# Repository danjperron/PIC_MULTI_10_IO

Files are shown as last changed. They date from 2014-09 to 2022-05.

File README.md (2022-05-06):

PIC_MULTI_10_IO
===============

RS-485 module with 10  I/O multi-function

Multi-Purpose RS-485 with Modbus Protocol using a small cpu PIC16F1827

Project compiled using MPlab X IDE with XC8 V2.36 using C90 standard (compiler optimization=2)

  The PIC  C code 
  
    - main.c             Main Source code.
    - IOCycle.c          Sensor cycle management.
    - DHT22.c            DHT11, DHT22 and AM2303 Temperature Sensor code.
    - DS18B20.c          Digital DS18B20 sensor code.
    - RCServo.c          R/C servo  PWM code.
    - CAPSENSE.c         Capacitive sensor code.
    - CRC16.c            Modbus Cyclic redundancy check code.

  The PIC Header
  
    - IOCycle.h
    - DHT22.h
    - DS18B20.h
    - RCServo.h
    - IOCONFIG.h         IO , Cpu Frequency and timing information header.

  The binary file
  
  - MULTI_IO_10_XT_1.06_9600.hex
  - MULTI_IO_10_XT_1.06_57600.hex

  No crystal
  - MULTI_IO_10_NOXT_1.06_57600.hex   
  - MULTI_IO_10_NOXT_1.06_9600.hex

  Add-on file for Raspberry Pi

    - PicModule.py        Python class interface.
    - configPIC.c         Application to configure each remote module.
    - test.c              Example code to interface the remote with libmodbus in C.

  The Schematic

    - MultiIO10.png  Electronic schematic.

  The GPL License

    - gpl.txt

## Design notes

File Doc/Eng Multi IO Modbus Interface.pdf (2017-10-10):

# MULTI IO 10

# RS-485 IO Interface with configurable function using a small Microchip cpu

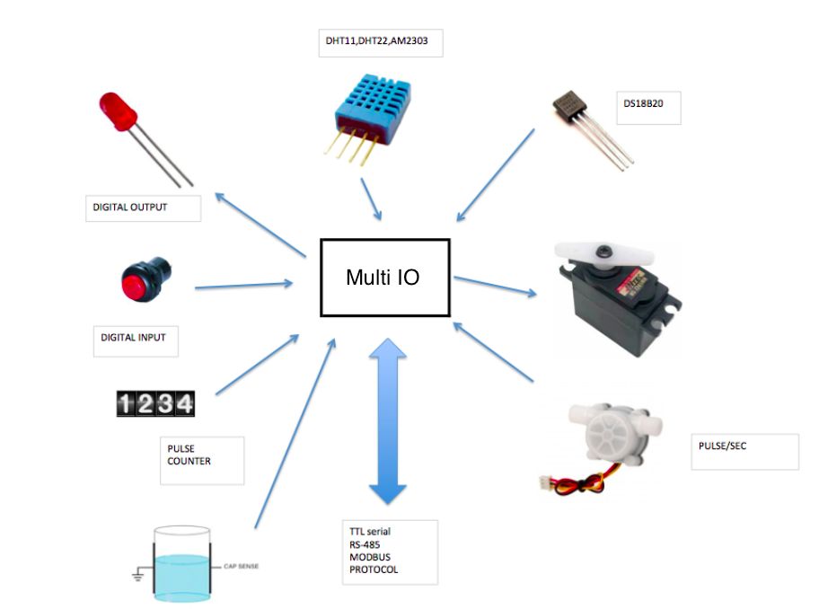
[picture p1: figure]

Daniel Perron
Avril 2014

## Preface

Often I need to have a special interface to connect a sensor far away of the computer which will interpret the signal. But instead of re-inventing the wheel all the times, I decide to create a small pcb with build-in screwable terminal with versatile IO configuration. This way I could change, by software, the functionalities of the pins.
I was tired of using an arduino, compile a special code and solder wire between the sensor and the arduino header.

I decide to use the RS-485 multipoint system which allow me to connect more than one module on the same cable and not been limited by short distance cable. The RS-485 cable could be extend up to 1200 meter without repeater.

Since Modbus protocol library was already available for Python and ‘C’, I decide to make the module compatible with Modbus. In theory, up to 247 modules could reside on the same bus but because of driver constraint, 64 modules is more or less the
maximum.

The 18 pins DIP PIC16F1827 will be the core cpu with 10 inputs or outputs signal with differents type of configuration possible,

- A/D 10 bits with 4 levels of voltage reference.
- DHT11, DHT22 ou AM2303 sensor interface.
- DS18B20 sensor interface.
- Internal capacitive frequency reader.
- Frequency and pulse counter reader.
- Simple input or output signal.
- 4 PWM output using 10 bits resolution.
- R/C PWM servo control.

## Step 1 - Raspberry Pi setup

An USB to Rs-485 interface it the easiest way to communicate with the Raspberry Pi. It is possible to use the internal serial ttl console but it is a little more complex since you need a way to control the direction of the signal.

If you want to use the built-in serial /dev/ttyAMA0 you will need to disable the debug and the serial console.

P.S. If you are using a USB adapter go to step 3.

1 - Disable the serial debug on /dev/ttyAMA0. (/dev/ttyS0 Pi3)
- Type ‘sudo raspi-config’.
- Select interface option.
- Select P6 serial.
- Select No for login shell.
- Select Yes to enable serial.
- Finish
- Reboot
pi@raspberrypi | ~ | $ | cd /boot
- Make a backup of cmdline.txt just in case.
pi@raspberrypi | /boot | $ | sudo cp cmdline.txt cmdline.txt.bk.1
- Edit the file cmdline.txt and remove everything related to
pi@raspberrypi | /boot | $ | sudo nano cmdline.txt
Remove console=ttyAMA0,115200 | kgdboc=ttyAMA0,115200
- Overwrite the file by pressing | ctrl-O | and exit ctrl-X | .

2 - Edit /etc/inittab and disable /dev/ttyAMA0 login console.

- Edit /etc/inittab.
pi@raspberrypi | /boot | $ | cd
pi@raspberrypi | ~ | $ | sudo nano /etc/inittab
- Find the line with /dev/ttyAMA0 (The last one).
- Add the character ‘#’ at the first column of the line. #T0:23:respawn:/sbin/getty -L ttyAMA0 115200 vt100
- Press | ctrl-O | to save and ctrl-X | to exit.
- Reload inittab using the command init | q | or just reboot.
pi@raspberrypi | ~ | $ | sudo init q

3 - Python minimalmodbus installation.

- Update debian
pi@raspberrypi | ~ | $ | sudo apt-get update
- Install python-pip.
pi@raspberrypi | ~ | $ | sudo apt-get install python-pip
pi@raspberrypi | ~ | $ | sudo apt-get install python3-pip
- Install minimalmodbus.
pi@raspberrypi | ~ | $ | sudo pip install -U minimalmodbus
pi@raspberrypi | ~ | $ | sudo pip-3.2 install -U minimalmodbus

4 - Install d’ intelhex. This is needed to program the cpu using the Pi.

sudo python3 -m pip install intelhex
- Get the source code.
pi@raspberrypi | ~ | $ | wget http://www.bialix.com/intelhex/intelhex-1.5.zip
- Unzip it.
pi@raspberrypi | ~ | $ | unzip intelhex-1.5.zip
- Install the Python module.
pi@raspberrypi | ~ | $ | cd intelhex-1.5/
pi@raspberrypi | ~/intelhex-1.5 | $ | sudo python setup.py install
pi@raspberrypi | ~/intelhex-1.5 | $ | cd

5 - Install libmodbus

pi@raspberrypi | ~ | $ | sudo | apt-get | install | libmodbus5 | libmodbus-dev

6- Now Let’s get the code to burn the PIC18F27 cpu.

pi@raspberrypi | ~ | $ | git clone https://github.com/danjperron/burnLVP.git

7- Download PIC_MULTI_10_IO from github.

pi@raspberrypi | ~ | $ | git clone https://github.com/danjperron/PIC_MULTI_10_IO.git

8- Reboot
sudo reboot

## Step 2 - Program the cpu

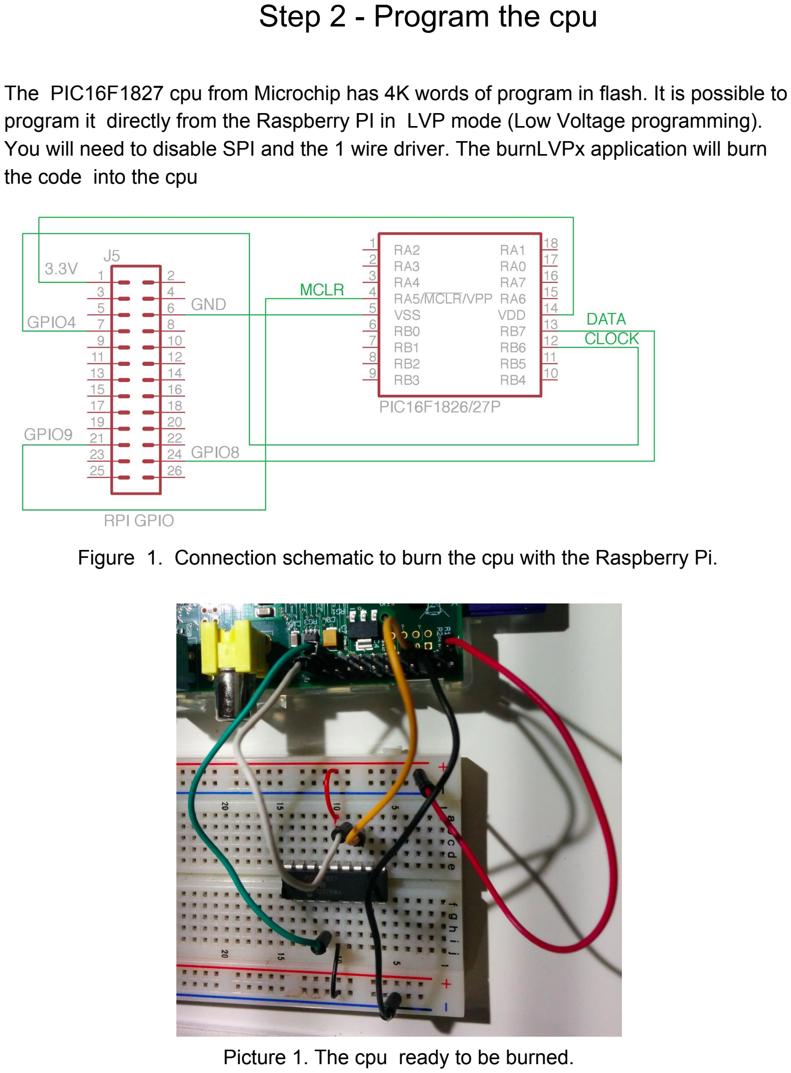
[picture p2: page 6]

The PIC16F1827 cpu from Microchip has 4K words of program in flash. It is possible to program it directly from the Raspberry PI in LVP mode (Low Voltage programming). You will need to disable SPI and the 1 wire driver. The burnLVPx application will burn the code into the cpu

Figure 1. Connection schematic to burn the cpu with the Raspberry Pi.

Picture 1. The cpu ready to be burned.

On the PCB it is possible to use the standard ICSP ,In circuit serial programming, connector. This connector will enable us to use external programmer like the PICKIT from Microchip and it is handy to re-program the cpu.

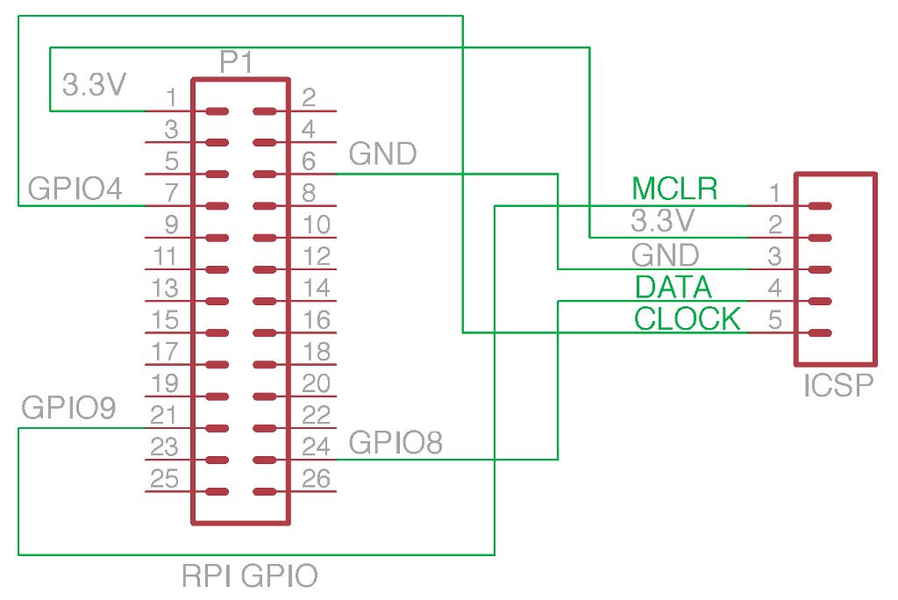
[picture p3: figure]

Figure 2. ICSP schematic connection.

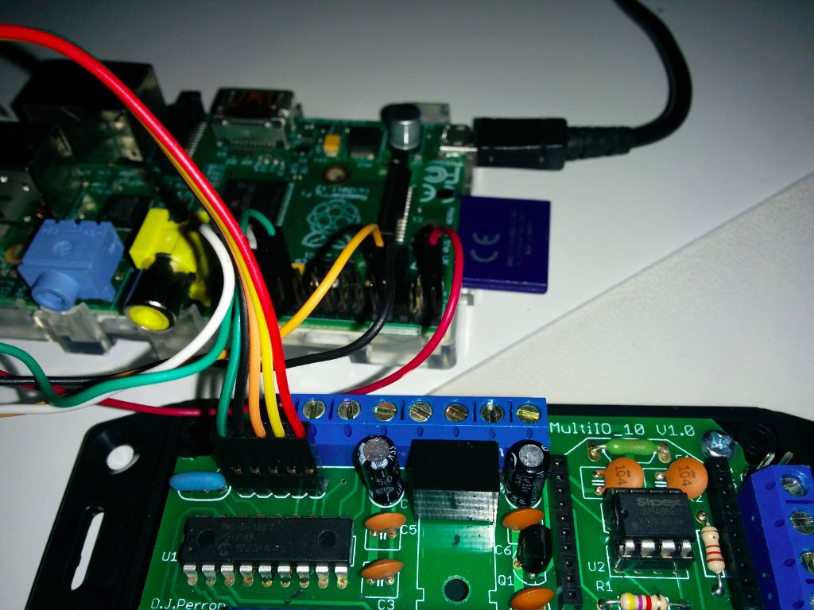
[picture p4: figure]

Picture 2. ICSP connection with the Raspberry PI.

N.B. You need to disconnect everything on IO3 and IO4 terminal. They are used by the ICSP. Please just use the 3.3V for direct connection with the Raspberry PI.

1 - Use burnLVPx.py to program the cpu.

- Connect the cpu according to Picture 1 or 2.
- Start burnLVPx with the current firmware.
pi@raspberrypi | ~ | $ | cd
pi@raspberrypi | ~ | $ | sudo | ./burnLVP/burnLVPx.py | PIC_MULTI_10_IO/FirmwareV1.04_57600Baud.hex

The output should look like this.
File " PIC_MULTI_10_IO/FirmwareV1.04_57600Baud.hex " loaded
Scan CPU
Check PIC12/16...
Cpu Id = 0x0
Revision = 0x5
Found PIC16F1827 from Cpu Family PIC12/16 Cpu Id: 0x27a0 revision: 5
Bulk Erase Program , Data. .... done.
Program blank check | Passed!
Data Blank check........Passed!
Writing Program | Done.
Program check | Passed!
Writing Data.Done.
Data check .Passed!
Writing Config..Done.
Config Check..Passed!
Program verification passed!
- Disconnect and remove the cpu or the ICSP.
- Add a sticker to mark the cpu.

## Step 4 - CPU verification

Once the cpu is programmed, it is time to test it with the Raspberry PI using the build-in serial port. A direct connection allow us to check the programmed cpu. The RS-485 interface is not needed .

The current firmware , FirmwareV1.04_57600Baud.hex, need an external 8Mhz ceramic resonator.

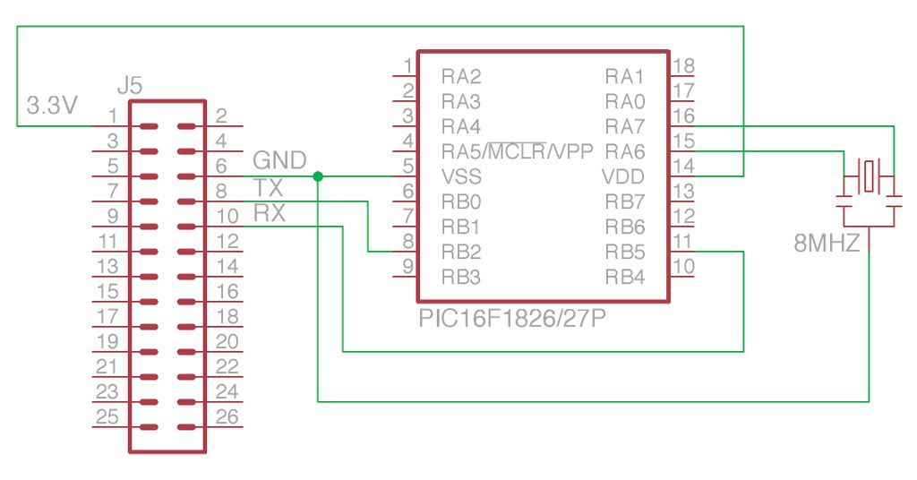
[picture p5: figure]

Figure 3. Direct TTL serial connection.

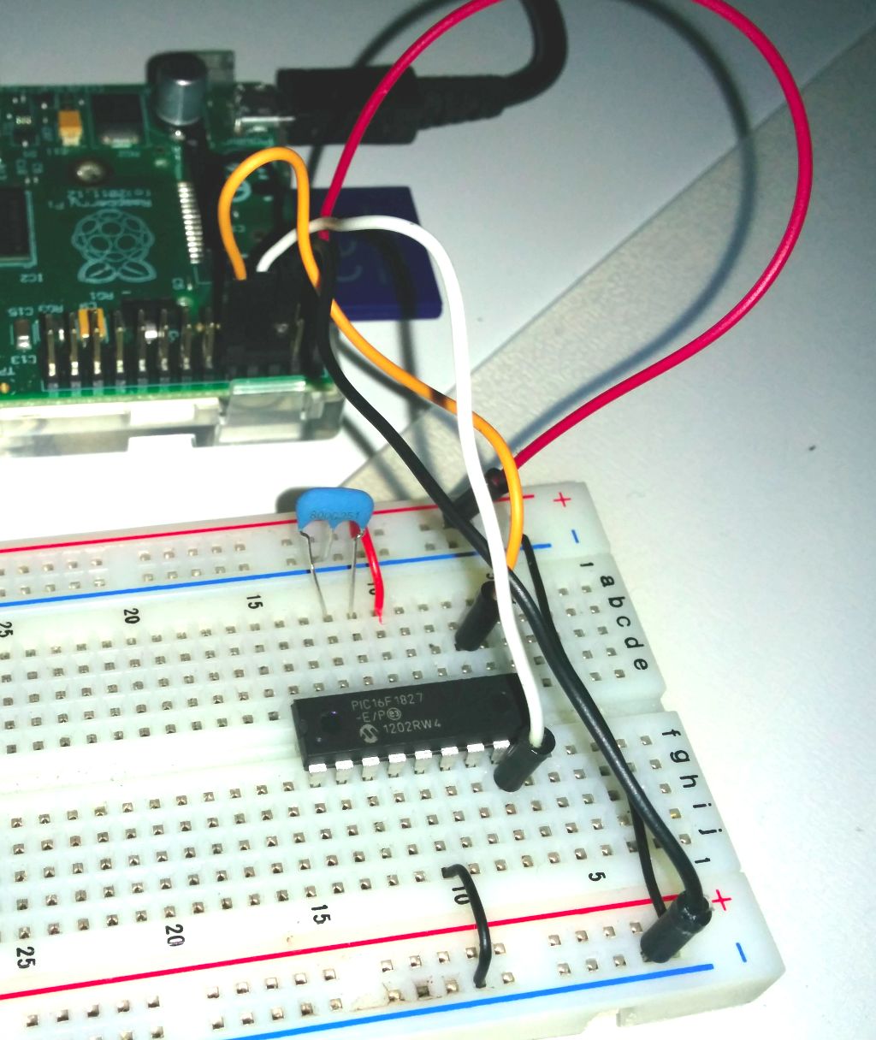
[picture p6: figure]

Picture 3. Direct cpu connection.

The “configPIC” will enable to test the cpu. You will need to compile it.

pi@raspberrypi | ~/PIC_MULTI_10_IO | $ | gcc | -I | /usr/include/modbus | \
> | configPIC.c | -o | configPIC | -l | modbus

P.S. put everthing on 1 line.
gcc -I /usr/include/modbus configPIC.c -o configPIC -l modbus

Let’s run the software with the correct parameters.

pi@raspberrypi | ~/PIC_MULTI_10_IO | $ | ./configPIC -d /dev/serial0 -b 57600

-d Device port specification.
-b Baud rate.
-t Waiting time out in microsecond.
For Xbee set timer to -t 200000

This is the application output response ,

PIC multi-purpose I/O MODBUS configuration Version 1.0 (c) Daniel Perron, April 2014 device:/dev/ttyAMA0 Baud Rate:57600

M) MODBUS scan
F) FLush buffer
A) Select Slave Module
C) Change Slave Address
0..9) Set IO mode
Q) Quit

Selected module :None

Press ‘M’! This will scan the RS-485 bus and it should find one module at the Press ‘M’. This command will scan the RS-485 bus and it should find one module at the address 127.

==== Scanning MODBUS
127 : Type 653A Multi Purpose 10IO

Now we will change the modbus address to something else. This way we could have more modules. Each module need to have a different modbus address.

Ok let;s change the address 127, the default, to address 1.

Press ‘A’ to select the module 127.

Select Module
Enter Slave Address ?127

It should respond with

Selected module :127

Press ‘C’ followed by 1 and [Enter].

=======Change Address
Enter new Slave Address for this module (1..127) ?1 Module is now on Address 1

The configPIC application will config each IO pins. The key 0 to 9 will select the IO pin.

ex: To change I/O 0 to be an 2V analog converter (A/D).

1 - Select the specific module . Press ‘A’ follow by the modbus address.
2 - Select the specific IO. Press the numeric key ‘0’...’1’.
The application will display a list of all mode possible the specific IO. Press 0 and 4 for 2V A/D.

Selected module :1
======= Change IO0 mode
0) ANALOGVDD | 1) ANALOG1V | 2) ANALOG2V
3) ANALOG4V | 4) INPUT | 5) INPUT PULLUP
6) OUTPUT | 7) PWM | 8) CAP SENSE OFF
9) CAP SENSE LOW 10) CAP SENSE MEDIUM 11) CAP SENSE HIGH
16) DHT11 | 17) DHT22 | 32) DS18B20
64) R/C SERVO | 128) COUNTER
Slave address 1 current IO0 mode is 4 : INPUT
Enter new configuration ?2
Module 1 IO0 set to 2: ANALOG2V

The key ‘L’ will display all the I/O configuration.

Selected module :127
=============
127 : Type 653A Multi Purpose 10IO
IO0: DHT22 | Temp: 24.2 Celsius Humidity: 57.1%
IO1: CAP SENSE HIGH [107 (0x006B)] [27481 (0x6B59)]
IO2: COUNTER | [0 (0x0000)] [0 (0x0000)] [0 (0x0000)]
IO3: COUNTER | [2 (0x0002)] [26823 (0x68C7)] [50 (0x0032)]
IO4: INPUT PULLUP | [1 (0x0001)]
IO5: ANALOG1V | [1023 (0x03FF)]
IO6: ANALOG2V | [672 (0x02A0)]
IO7: OUTPUT | [0 (0x0000)]
IO8: R/C SERVO | [1000 (0x03E8)]
IO9: DS18B20 | Temp: 23.8 Celsius

## I/O specification and modbus

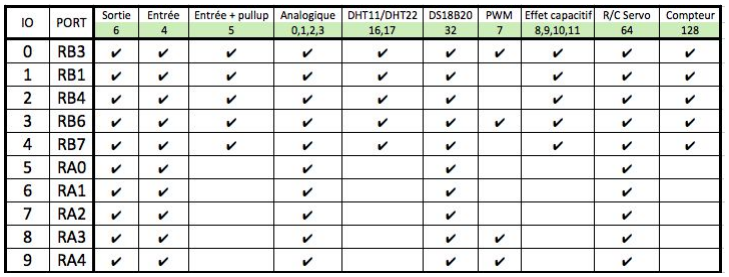
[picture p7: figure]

Figure 4. Configuration table

The modbus address and the I/Os configuration are stored in flash memory of the cpu. They are permanently store.

This is the configuration constant list in Python.

IOCONFIG_ANALOGVDD= 0
IOCONFIG_ANALOG1V= 1
IOCONFIG_ANALOG2V= 2
IOCONFIG_ANALOG4V= 3
IOCONFIG_INPUT= 4
IOCONFIG_INPUT_PULLUP= 5
IOCONFIG_OUTPUT= 6
IOCONFIG_PWM= 7
IOCONFIG_CAP_SENSE_OFF= 8
IOCONFIG_CAP_SENSE_LOW=9
IOCONFIG_CAP_SENSE_MEDIUM=10 IOCONFIG_CAP_SENSE_HIGH=11
IOCONFIG_DHT11= | 16
IOCONFIG_DHT22= | 17
IOCONFIG_DS18B20= 32
IOCONFIG_SERVO= 64
IOCONFIG_COUNTER= 128

A/D | MODE
IOCONFIG_ANALOGVDD | =0 ( VRef= VDD)
IOCONFIG_ANALOG1V | =1 ( VRef=1.024V)
IOCONFIG_ANALOG2V | =2 ( VRef=2.048V)
IOCONFIG_ANALOG4V | =3 ( VRef=4.096V)

A 10 bits value will be returned.

The formula is,

Voltage read = A/D value * Reference Voltage / 1023;

Python

readSensor(Pin) | => this function came from PicModule.py

and it will called
module.read_registers(Pin * 16 , 1, 4)[0]

Read register[16 * Pin] with modbus function 4

Language | C
| | uint16_t MB_Register[3];
if(modbus_read_input_registers(mb,Pin*16,1,MB_Register)>=0) {
// The MB_Register[0] will hold the 10 bits conversion }

ex: Read Temperature on IO0 module 1.

import time
import PicModule
remote1 = PicModule.PicMbus(1,Baud=57600,Device=’/dev/serial0’)

#ioconfig are set once and store into the eerom

# we just need to check it and change it if it is not ok ioconfig = remote1.readConfig(0)

if ioconfig != remote1.IOCONFIG_ANALOG1V: remote1.config(0,remote1.IOCONFIG_ANALOG1V) time.sleep(0.3) #need to wait for eerom writing

AnalogValue= remote1.readSensor(0)
print("TMP35 : {:5.1f}°C".format(AnalogValue/10.0))

On the A/D conversion system, two special registers could be read to get power voltage and build-in diode temperature sensor.

Modbus register 0x1000 => Return A/D conversion of 2.048V using VDD has Vref.

Python

readVRef2V()

module.read_registers(0x1000,1,4)[0]

language C

uint16_t MB_Register[3];
if(modbus_read_input_registers(mb,0x1000,1,MB_Register)>=0) {
// register MB_Register[0] hold 10 bits A/D.
}

ex: Read the CPU Voltage.

import PicModule
remote1 = PicModule.PicMbus(1,Device=’/dev/serial0’) A2D_VRef = remote1.readVRef2V()
print("VDD : {:5.2f}V".format(2.048*1023.0/A2D_VRef))

The same method could be used to read the thermal diode.

Python

readDiode()

module.read_registers(0x1000,1,4)[0]

language C

uint16_t MB_Register[3];
if(modbus_read_input_registers(mb,0x1001,1,MB_Register)>=0)
| {
// register MB_Register[0] hold 10 bits A/D.
| }

DIGITAL | INPUT | MODE
IOCONFIG_INPUT | =4
IOCONFIG_INPUT_PULLUP | =5 ( Weak pull up from cpu)

The IOCONFIG_INPUT_PULLUP is only available for IO0,IO1,IO2,IO3 et IO4. One small pull-up current will hold the input to VDD.

Each I/O in digital mode are define has 0 or 1.

Python

readIO(Pin)

module.read_bit(Pin)

Language | C
| | | | | | | | | | | | | uint16_t | MB_Register[3];
if(modbus_read_input_registers(mb,Pin*16,MB_register)>=0)
| | {
| | | | | | …= | MB_Register[0]; | | // | retourne | 0 | ou | 1
| | }

N.B. Digital IO could be read or set using an 16 multiplier offset.

ex: To read IO7

#Let’s assume that the configuration is already set to digital input.

import PicModule
remote1 = PicModule.PicMbus(1,Baud=57600,Device=’/dev/serial0’)

print(“IO0: {}”,remote1.readIO(0))

DIGITAL | OUTPUT | MODE
IOCONFIG_OUTPUT | =6

This mode will set IO to digital output signal.

Python

writeIO(Pin, valeur)

module.write_bit(Pin,valeur)

Language C

if(modbus_write_bit(mb,Pin,Value)>0)

| | {
| | | | | | … | it | is | done!
| | }

ex: Create three pulse on IO1 module 2 with an USB to RS-485 adapter.

import time
import PicModule
remote2 = PicModule.PicMbus(2,Baud=57600,Device=’/dev/ttyUSB0’) #Let’s assume that the configuration is already set.

for pulse in range(3):
remote2.writeIO(1,1)
time.sleep(0.1)
remote2.writeIO(1,0)
time.sleep(0.1)

CAPACITIVE | MODE
IOCONFIG_CAP_SENSE_OFF | =8
IOCONFIG_CAP_SENSE_LOW | =9
IOCONFIG_CAP_SENSE_MEDIUM | =10
IOCONFIG_CAP_SENSE_HIGH | =11

A running oscillator will clock at the determine frequency will depends on capacitive load. This mode will read count. Four mode of power are available with one with no generator.
The format is 32 bits ( 4 registers) and the time base is 0.1 sec.

Python

readSensor(Pin)

module.read_long(Pin * 16,4,False)

ex: Read Frequency on IO0 et IO1

import time
import PicModule
remote1 = PicModule.PicMbus(1)

#assume that IOCONFIG1 et IOCONFIG0 are in mode IOCONFIG_CAP_SENSE_HIGH

print(“Cap sense IO0 : {}”.format(remote1.ReadSensor(0)) print(“Cap sense IO1 : {}”.format(remote1.ReadSensor(1))

Dielectric constant differs from the type of material . With this mode it is possible to calculate level from a container. You will need to get the count readout any multiple position and compensate for temperature .

DHT | SENSOR | MODE
IOCONFIG_DHT11 | =16
IOCONFIG_DHT22 | =17 | (Also AM2303 type)

Read DHT11 or DHT22 temperature sensor.

Two registers will return Temperature and humidity.

Python

| | | | | | | readDHT(Pin)
return None => No Sensor reading.
return [humidity, temperature]

module.read_register(Pin * 16,3,4) #this is a generic function return registers
[0] 0xFFFF => No sensor 1=> sensor value OK
[1] Humidity raw value
[2] Temperature raw value

Language C

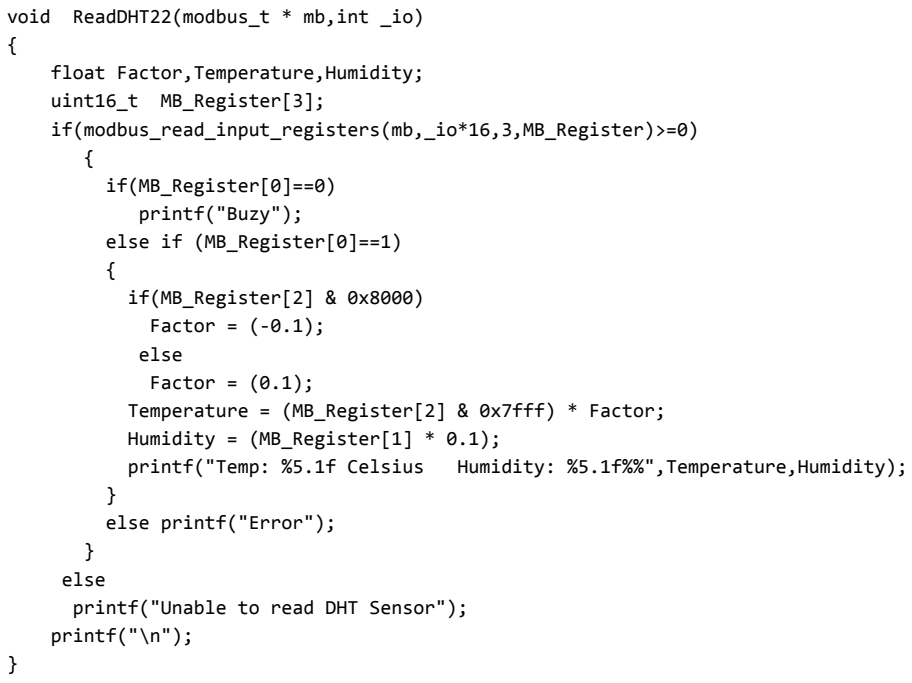
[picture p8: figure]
void ReadDHT22(modbus_t * mb,int _io); float Factor,Temperature,Humidity;; uint16_t MB_Register[3];; if(MB_Register[0]==0); printf("Buzy");; else if (MB_Register[0]==1); if(MB_Register[2] & 0x8000); Factor = (-0.1);; else; Factor = (0.1);; Humidity = (MB_Register[1] * 0.1);; else printf("Error");; printf("Unable to read DHT Sensor");; printf("\n");

if(modbus_read_input_registers(mb,_io*16,3,MB_Register)>=0)

Temperature = (MB_Register[2] & 0x7fff) * Factor;

printf("Temp: %5.1f Celsius Humidity: %5.1f%%",Temperature,Humidity);

ex: Read DHT22 sur IO 0 Module 1

import time
import PicModule
remote1 = PicModule.PicMbus(1)

result = remote1.readDHT(0)
if result is None:
print(“Error ON DHT Sensor! Bad Config or sensor not connected”) else:
print(“Humidity: {5.1f}%”.format(result[0])) print(“Temperature:{5.1f}°C”.format(result[1]))

P.S. Care have to be taken when you power up the DHTXX sensor. It won’t work if it is not let’s Idle high on power up. Better to config the sensor first, connect the sensor and power it up.

Also to use to much counter and R/C servo. This will increase the interrupt lag and made the sensor unreadable.

THE | DS18B20 | MODE
IOCONFIG_DS18B20 | =32

Read DS18B20 temperature sensor.

N.B. IO5, IO6, IO7, IO8 and IO9 will need a pull-up resistor (~4k7)

Python
| | | | | | | | | readDS18B20(Pin)

return None => No sensor
retourn The temperature

Language C

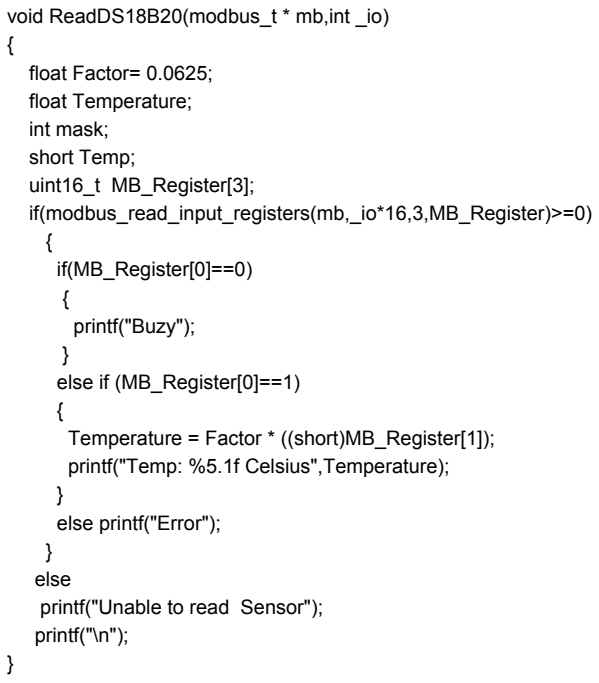
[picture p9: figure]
void ReadDS18B20(modbus_t * mb,int _io) {; float Factor= 0.0625; float Temperature; int mask; short Temp; uint16_t MB_Register[3];; if(MB_Register[0]==0) {; printf("Buzy");; } else if (MB_Register[0]==1) {; } else printf("Error");; } else printf("Unable to read Sensor"); printf("\n");

if(modbus_read_input_registers(mb,_io*16,3,MB_Register)>=0)

Temperature = Factor * ((short)MB_Register[1]); printf("Temp: %5.1f Celsius",Temperature);

ex: Read DS18B20 sur IO0 Module 1

import time
import PicModule
remote1 = PicModule.PicMbus(1)
result = remote1.readDS18B20(0)
if result is None:
print(“Error ON DS18B20 Sensor! Bad Config or sensor not connected”) else:
print(“Temperature:{6.2f}°C”.format(result))

The | | R/C | SERVO | MODE
IOCONFIG_SERVO | =64

Control R/C servo module.

Set the register in micro-second step.

To turn OFF servo, siply set te register to 0.

The default range for R/C servo are 500 to 2500µs

It is possible to play between 1 to 20000 but the behavior could be really bad.

Python

RCServo(Pin,value)

Language C

modbus_write_register(mb,Pin * 16, value);

ex: Set ALL R/C servo from module in center position (1000us).

import PicModule
remote1 = PicModule.PicMbus(1) remote1.RCServo(0,1000)

THE | COUNTER | MODE
IOCONFIG_COUNTER | =128

Count digital pulse in 32 bits resolution. Also return a Pulse/sec frequency couter (16 bits).

Python

readSensor(Pin)

[0]= MSB 16 bits Unsigned int counter.
[1]= LSB 16 bits Unsigned int counter.
[2]= Pulse per second counter. (The frequency).

ex: Read COUNTER on IO0

import PicModule
remote1 = PicModule.PicMbus(1)
#assume ioconfig on IO0 to be IOCONFIG_COUNTER result = remote1.readSensor(0)

print(“Pulse/sec = {}”.format(result[2]);
print(“Total Count ={}”.format(result[0] * 65536 + result[1]);
Language | C
| | | | | | | | | | | | | | | | | | | | | | unsigned long totaliser;
uint16_t Frequence;
uint16_t MB_Register[3];
if(modbus_read_input_registers(mb,Pin*16,3,MB_Register)>0)
{
totaliser = ((unsigned long)MB_Register[0])<<16 | MB_Register[1]);
Frequence = MB_Register[2];
}

It is possible to reset the counter.

python

resetCounter(Pin)

module.write_register(Pin,0,0,6) #this is the generic function called by resetCounter()

Language C

modbus_write_register(mb,Pin,0);

A webpage using 3 modules of 8 relays.

This is a small project using a webpage powered by webiopi to control 24 relays using three modules.

Install webiopi
pi@raspberrypi | ~ | $wget | http://sourceforge.net/projects/webiopi/files/WebIOPi-0.7.0.tar.gz
pi@raspberrypi ~ $tar | -xzvf WebIOPi-0.7.0.tar.gz
pi@raspberrypi ~ $cd | WebIOPi-x.y.z
pi@raspberrypi ~ | sudo ./setup.sh

Set the Raspberry-pi to enable webiopi on power up. Raspberry Pi.
pi@raspberrypi | ~ | $sudo | update-rc.d | webiopi | defaults

The first time we will need to reboot or start webiopi manually.
pi@raspberrypi | ~ | $sudo | service | webiopi | start

Let’s change the script to include our own python script to access the modbus module and let’s set the system to set WebRelais.html has the default webpage.

pi@raspberrypi | ~ | $cd | /etc/webiopi
pi@raspberrypi | ~ | $sudo | nano | config

[SCRIPTS]
# | Load | custom | scripts | syntax | :

# | name | = | sourcefile

# | | | each | sourcefile | may | have | setup, | loop | and | destroy | functions | and | macros

myscript | = | /home/pi/WebRelais.py
# | Use | welcome-file | to | change | the | default | "Welcome" | file

welcome-file | = | WebRelais.html

WebRelais.py is in the github PICMulti_10_IO. you just need to copy it over.

pi@raspberrypi | ~ | $ | cp | /home/pi/PIC_MULTI_10_IO/WebRelais.py | /home/pi
pi@raspberrypi | ~ | $ | cp | /home/pi/PIC_MULTI_10_IO/PicModule.py | /home/pi
pi@raspberrypi | ~ | $ | chmod | +x | /home/pi/WebRelais.py
pi@raspberrypi | ~ | $ | chmod | +x | /home/pi/PicModule.py

And let’s transfert de webpage to /usr/share/webiopi/htdocs
pi@raspberrypi | ~ | $ | cd | /usr/share/webiopi/htdocs
pi@raspberrypi | ~ | $ | sudo | cp | /home/pi/PIC_MULTI_10_IO/WebRelais.html | .

Restart webiopi
pi@raspberrypi | ~ | $ | sudo | service | webiopi | restart

The webpage should be available at the Raspberry PI IP on PORT 800.

You could change or remove the password by editing or deleting /etc/webiopi/passwd.

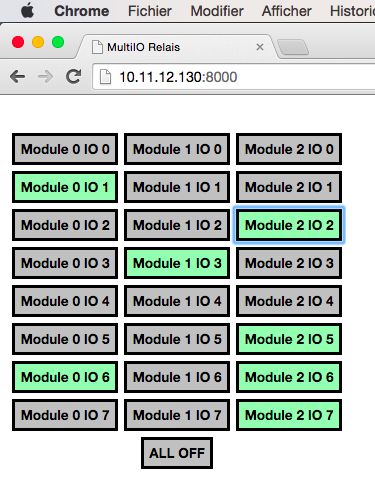
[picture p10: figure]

Ok IO0 to IO7 are connected to relay. We could use IO8 to check the temperature with a DS18B20. We will need to add a 4k7 pull-up resistor.

From a previous project, I do have code to display temperature using RDTOOL and HighChart.

InstallHighChart and rrdtool.

pi@raspberrypi | ~ | $ | sudo | apt-get | install | rrdtool
pi@raspberrypi | ~ | $ | wget | | http://code.highcharts.com/zips/Highcharts-3.0.9.zip
pi@raspberrypi | ~ | $ | sudo | mkdir | /usr/share/webiopi/htdocs/charts
pi@raspberrypi | ~ | $ | sudo | unzip | Highcharts-3.0.9.zip | -d | /usr/share/webiopi/htdocs/charts

Do a test to check the install
http://raspberrypi.local/charts/index.htm (Not “html” but “htm”).

raspberrypi.local is the Raspberry Pi. You could use avachi to set a local name

install libnss-mdns

pi@raspberrypi | ~ | $ | sudo | apt-get | install | libnss-mdns

This way you will have access to the Raspberry PI using it’s identificatio name + “.local”. P.S. It won’t work with adroid device.

If you want to change the name of your raspberry PI to WebPi for example

sudo | hostname | WebPi
sudo | nano | /etc/hosts | | | | | | and | change | raspberrypi | to | WebPi
sudo | nano | /etc/hostname | | and | change | raspberrypi | to | WebPi
and “reboot”

Now that HightCharts et rrdtool are installed , ww will modify WebRelais.py and add historique.html.

pi@raspberrypi ~ $ sudo service webiopi stop
pi@raspberrypi ~ $ sudo rm /home/pi/WebRelais.py
pi@raspberrypi | ~ | $ | cp | /home/pi/PIC_MULTI_10_IO/WebRelais.2.py | | /home/pi/WebRelais.py
pi@raspberrypi | ~ | $ | cd | /usr/share/webiopi/htdocs
pi@raspberrypi | ~ | $ | sudo | cp | /home/pi/PIC_MULTI_10_IO/historique.html | .

To prevent premature wear of the SD card, we will create a ramdisk to handle temporary file create by rrdtool.

in /etc/fstab, add the line in yellow,

pi@raspberrypi | ~ | $ | sudo | mkdir | /usr/share/webiopi/htdocs/temperature
pi@raspberrypi | ~ | $ | sudo | nano | /etc/fstab
proc | /proc | proc defaults | 0 | 0
/dev/mmcblk0p1 /boot | vfat defaults | 0 | 2
/dev/mmcblk0p2 / | ext4 defaults,noatime 0 | 1
tmpfs /usr/share/webiopi/htdocs/temperature tmpfs defaults,noatime,nosuid,mode=0755,size=1m 0 0

The ramdisk will be link at /usr/share/webiopi/htdocs/temperature.

Restart the RPi to check if the ramdisk will be mounted properly.

A already made script will create the rrdtool database. But first let’s create /home/pi/data

pi@raspberrypi | ~ | $ | mkdir | data
pi@raspberrypi | ~ | $ | /home/pi/PIC_MULTI_10_IO/createdata.sh

And restart webiopi

pi@raspberrypi | ~ | $ | sudo | service | webiopi | start

And Check the webpage http:://RaspberryPi.local:8000/historique.html

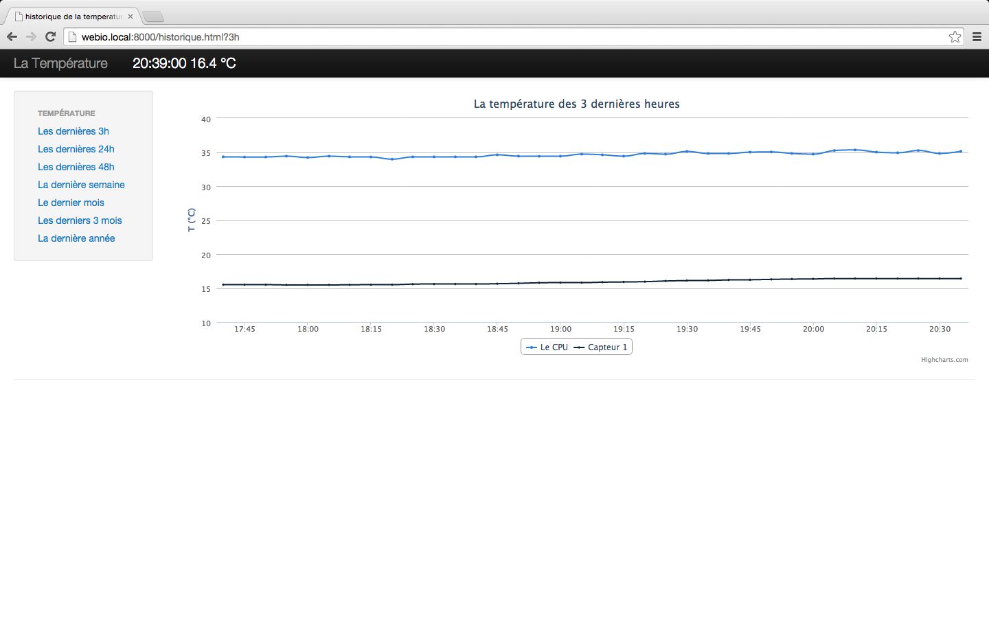
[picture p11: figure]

## APPENDIX

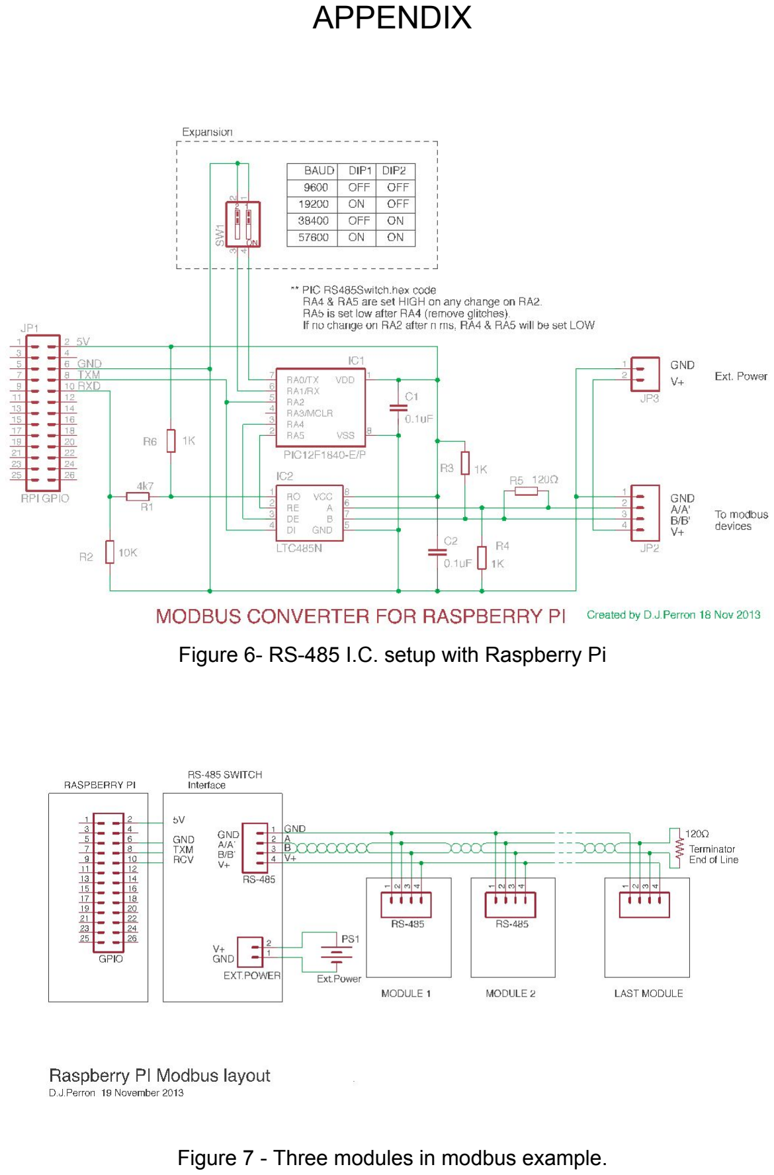
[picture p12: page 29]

Figure 6- RS-485 I.C. setup with Raspberry Pi

Figure 7 - Three modules in modbus example.

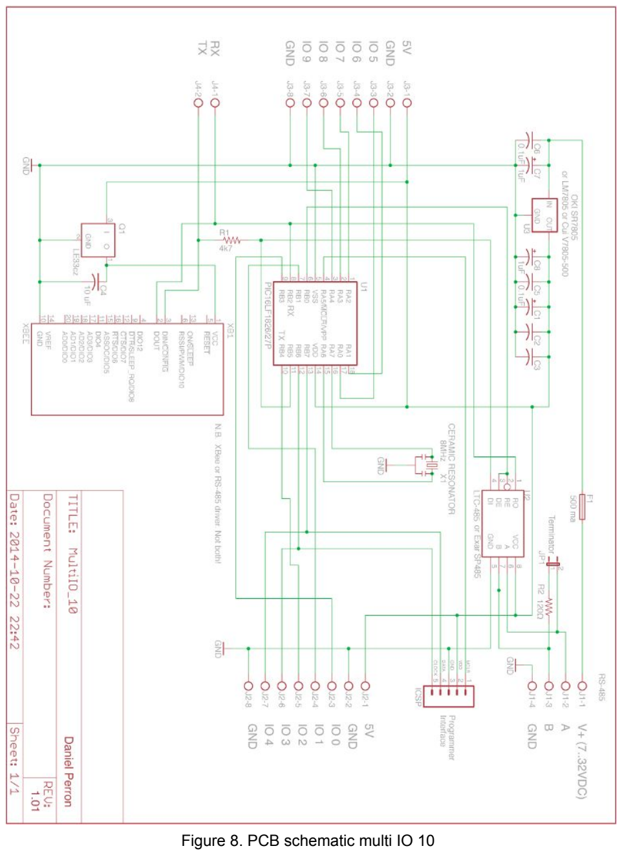
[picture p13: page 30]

Figure 8. PCB schematic multi IO 10

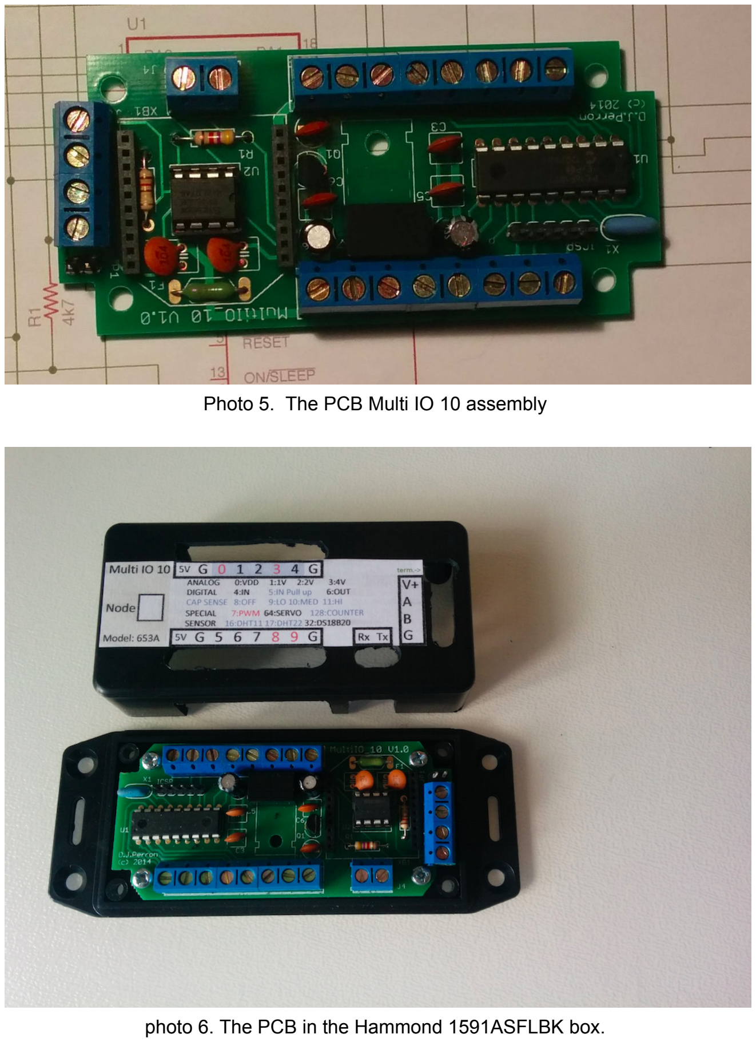
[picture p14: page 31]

Photo 5. The PCB Multi IO 10 assembly

photo 6. The PCB in the Hammond 1591ASFLBK box.

## Reference

Modbus Protocol Reference Guide Modicom PI-MBUS-300 Rev. H
AEG SCHNEIDER
AUTOMATION
http://web.eecs.umich.edu/~modbus/documents/PI_MBUS_300.pdf

PIC12F1840
Microchip
8-Pin Flash Microcontrollers with XLP Technology http://ww1.microchip.com/downloads/en/DeviceDoc/40001441D.pdf

LTC485
Linear Technology
Low power RS485 Interface transceiver http://cds.linear.com/docs/en/datasheet/485fi.pdf

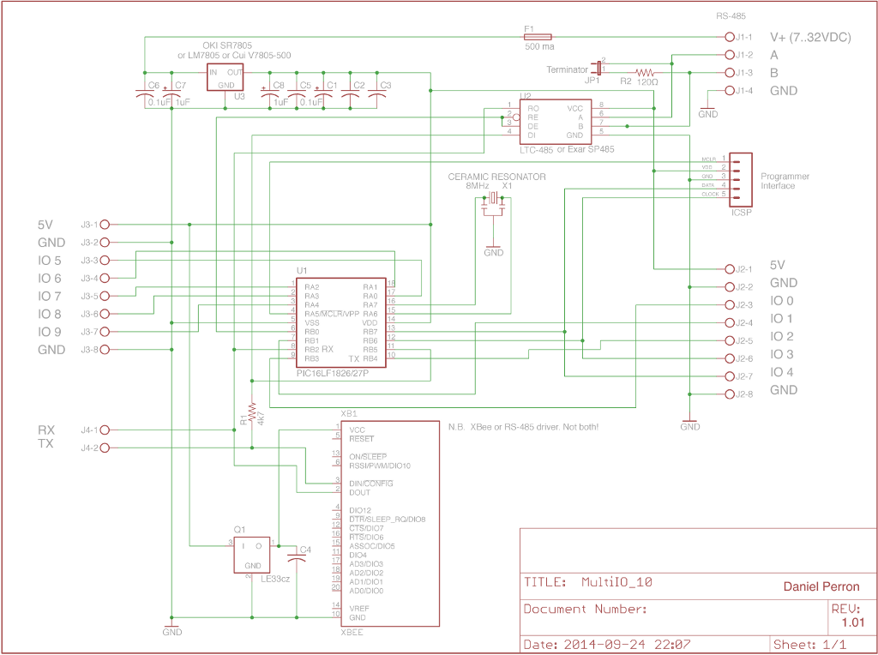
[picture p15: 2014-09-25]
MultiIO10.png

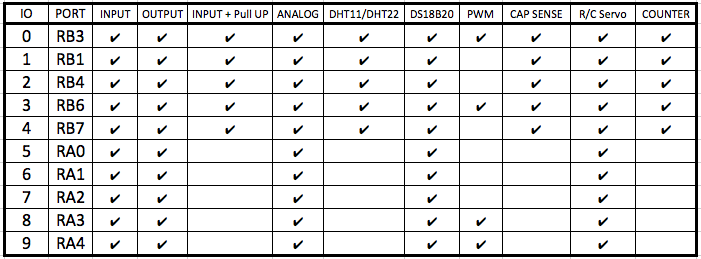
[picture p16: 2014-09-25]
Multi_10_IO_config.png

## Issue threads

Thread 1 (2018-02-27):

Capacitor values

stuarteiffert, 2018-02-27:
Hi Daniel,

The values aren't listed for all capacitors in the PCB schematic.
C1, C2, and C3 are blank.
From the picture of the assembly all three appear to be 0.1 μF, is this correct?

Also, what voltage did you use for the external power?
Looking at the datasheet for the DC/DC converter cui V7805-500, it expects a nominal voltage of 24V, and the capacitor values seem to depend on this, with the capacitance from Vin to GND being 10μF/50V and Vout to GND being 22μF/10V.
From the schematic and pictures, it seems that Vin to GND (C6 + C7) = 1.1μF and Vout to GND (C1 + C2+ C3 +C5 +C8) = 1.4μF, which wouldn't make sense for any Vin above 5.5V (unless I've misread something).

Thanks,
Stuart

danjperron, 2018-02-27:
Well All depends what you need!

What will be you regulator? What kind of  Power supply you will provide.

In reality capacitor voltage indicate the maximum Voltage . So a 100V will work on 3.3V.

I check All my capacitor and they are all 50V.

If you are using voltage below 12V use a linear regulator because the Cui is very expensive unless you are using the 5V for R/C servo or you draw too much of it.

I did have a problem with the Xbee and I had to add a 10µF between the gnd and 3.3V. (Too much power oscillation).

This is a picture of two of my test boards . One has a lm7805 and the other Cui DC/DC regulator.

I do have sme with a single 7805 but  I design one with
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

stuarteiffert, 2018-02-28:
I was planning on using a 12V DC battery supply (so capacitor sizing on the regulator is not as important) and including some servos, so I went with the Cui for now.

The pictures of your test boards you mentioned aren't visible for me by the way.

Thanks,
Stuart

danjperron, 2018-02-28:
https://dl.dropboxusercontent.com/s/ybdbr5cnugwys58/multi_IO_using%207805%20or%20Cui%20regulator.jpg

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

danjperron, 2018-02-28:
Just in case you didn't know about my google drive doc
https://docs.google.com/document/d/1lXswQlaUgRb-156ZBXZssPgz_-Iv_EBm5P-c_YVQfOA/edit?usp=sharing

I should put it  in the  readme page

stuarteiffert, 2018-02-28:
Thanks!

Closed 2019-06-21.

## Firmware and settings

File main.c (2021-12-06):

/* 
 * File:   main.c
 * Author: daniel
 *
 * Created on 27 mars 2014, 21:59
 * 
 *  Version 1.05 November 2021
 *  - add COUNTER_PULLUP feature
 *  - increase delay in ReadDS18B20
 * 
 *  Version 1.04 October 2017
 *  - Fix start signal for DHT22 and DHT11. Start pulse is 20ms
 *  - Fix upper and lower case .c and .h file
 *  - Fix signed/unsigned warning
 *  - Fix memory overlap between Received buffer and DHT22 buffer
 */

#ifdef __XC__
#include <xc.h>
#else
#include <htc.h>
//#include <stddef.h>
#endif

#include "IOCycle.h"
#include "DHT22.h"
#include "DS18B20.h"
#include "CAPSense.h"
#include "IOConfig.h"
#include "RCServo.h"
/////////////////////////////////////////////////////////////////////////////////////////////////////////////////////////
//  MultiIO10   Multifunction 10 pins
//
// Simple program with different function on each pin
// using RS-485 with modbus protocol to communicate
// 
//
//  List of IO mode
//
//
// 1- Digital input.  ( IO0..IO4 could have PULL_UP resistor)
// 2- Digital output.
// 3- Analog input withc selectable reference voltage.
//    (1.024,2.048,4.096V and  VDD).
// 4- R/C servo pwm mode . select step value in usec.
//    ( Servo use software timer).
// 5- PWM output  with 10 bits resolution (0..1023).
//     Hardware comparator at 1.9Khz cycle ferquency
// 5- Reading of DHT11,DHT22 and AMM2302 temperature sensor.
// 6- Reading of DS18B20 temperature sensor
// 7- Cap sensor signale with 4 different power setting.
// 8- Pulse counter. Give Pulse count at Pulse/sec.


//   Date: Dec 1 2021
//   Version 1.06
//   Processeur PIC16F1827
//   Compiler XC8 V1.44 or lower
//   add CRC check on DS18B20 and counter pull-up option

//   Date: 27 Mars 2014
//   programmer: Daniel Perron
//   Version: 1.0
//   Processeur: PIC12F1827
//   logiciel de compilation:  Microchip MPLAB  X IDE (freeware version)
//
//   The system use serial communication at 57600 BAUD with modbus protocol.
//  
//   Pin RB0 control the serial communication direction.
//
//
//   MODBUS REGISTER LIST
//
//
/////  Modbus Function  01 & 02
//
//  Lire IO0 to IO9
//
//  Modbus [SLA][1][0][A][0][1][CRC]
//
//  SLA - Adresse
//  A   - 0=IO0 1=IO1 ... 9=IO9
//  CRC - Cyclical redundancy check.
//
//  Ex:   Python Read IO0 Bit on slaveAddress module 1 (using PicModule.py)
//
//    import PicModule
//    m1 = PicModule.PicMbus(1)
//    m1.readIO(0)
//
//
//
/////  Modbus Function 3
//
//  Modbus [SLA][3][0][A][0][1][CRC]
//
//  A =
//    0..9 :  Read  R/C servo or PWM value of IO
//     160 :  Read slave modbus address
//     250 :  Read Software version
//     251 :  Read Software Id number
// (0x100 .. 0x109):   Read IO configuration Mode
// 
//
//
// Ex:  Python
//   Lire numéro d'identification du logiciel
//   m1.readId():
//
//   or  the long way
//
//   m1.module.read_register(251,0,3);
//
//
///// Modbus Fonction 4
//
//  Modbus [SLA][4][0][A][0][Number of register][crc]
//

  // Function 4  Read Current Register
  //
  // Address 0x1000:  Current VRef 2.048V A/D value
  // Address 0x1001:  Current Build-in Temperature Sensor
  // Address 0xn0:  Read current IOn
//  A =  0x00N0:  Read IO Sensor data where N is the IO id number.
//       0x1000:  Read the 2.048V ref with the VDD has reference.
//       0x1001:  Read build-in temperature diode. (VDD=Vref).
//
//
//  Ex: Read DS18B20 Sensor At IO2
//
//     m1.readDS18B20(2)
//
//
//
///// Modbus Fonction 5
//
//  Modbus [SLA][5][0][A][0][DATA][crc]
//
//  A = 0..9 : Set IO bit output
//
//
///// Modbus Fonction 6
//
//  Modbus [SLA][6][0][A][16 bits DATA][CRC]
//
//  A = 0..9:  Set R/C Servo or PWM digital output
//             Also clear COUNTER (In counter Mode)
//       160:  Set new modbus slave address
// 0x100..0x10a:  Set new IO configuration  (IOCONFIG.H)

//
//  ex:    Change IO0 configuration to read DHT22 SENSOR
//  
//   m1.config(0,m1.IOCONFIG_DHT22)
// 
//

#define SOFTWARE_ID      0x653A
#define RELEASE_VERSION  0x0106



///////////////////  How to program the IC.
//
//    1 - Use MPLAB with pickit 3  (need version 8.90 at least)
//  or
//    2 - Use standalone pickit2 v 2.61 (Select the I.C. and load the corresponding hex file).
//  or
//    3 - Use Raspberry Pi board  with burnVLP.py . Software available from https://github.com/danjperron/burnLVP
//
////////////////////////////////////  GPL LICENSE ///////////////////////////////////


/*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
 <http://www.gnu.org/licenses/>.
*/



/*  COMMUNICATION PROTOCOL

     rate 57600 , 8 bits data , no parity
    
*/
//////////////////////////  PORT DESCRIPTION
/*
 * IO5 RA0
 * IO6 RA1
 * IO7 RA2
 * IO8 RA3
 * IO9 RA4
 *     RA5    MCLR (RESET)
 *     RA6    CRYSTAL CLOCK
 *     RA7    CRYSTAL CLOCK
 *     RB0    RS-485 DIRECTION
 * IO1 RB1
 *     RB2    SERIAL IN
 * IO0 RB3
 * IO2 RB4
 *     RB5    SERIAL OUT
 * IO3 RB6
 * IO4 RB7
 *
 * P.S. ONLY IO0..IO4 support Counter, Pull-up, Cap Sense and DHT type sensor.
 *
 *
*/



//rs-485 data direction

#define TXM_ENABLE   RB0



#ifndef BORV_LO
#define BORV_LO BORV_19
#endif

#define iabs(A)  (A<0 ?  (-A) :  A)


// CONFIG1

#ifdef USE_EXTERNAL_XTAL
    #pragma config FOSC= HS
#else
    #pragma config FOSC = INTOSC // Oscillator Selection (INTOSC oscillator: I/O function on CLKIN pin)
#endif
#pragma config WDTE = ON // Watchdog Timer Enable (WDT enabled)
#pragma config PWRTE = OFF // Power-up Timer Enable (PWRT disabled)
#pragma config MCLRE = ON // MCLR Pin Function Select (MCLR/VPP pin function is MCLR)
#pragma config CP = OFF // Flash Program Memory Code Protection (Program memory code protection is disabled)
#pragma config CPD = OFF // Data Memory Code Protection (Data memory code protection is disabled)
#pragma config BOREN = ON // Brown-out Reset Enable (Brown-out Reset enabled)
#pragma config CLKOUTEN = OFF // Clock Out Enable (CLKOUT function is disabled. I/O or oscillator function on the CLKOUT pin)
#pragma config IESO = OFF // Internal/External Switchover (Internal/External Switchover mode is enabled)
#pragma config FCMEN = ON // Fail-Safe Clock Monitor Enable (Fail-Safe Clock Monitor is enabled)

// CONFIG2
#pragma config WRT = OFF // Flash Memory Self-Write Protection (Write protection off)
   
#ifdef USE_EXTERNAL_XTAL
  #pragma config PLLEN = ON // PLL Enable (4x PLL enabled)
#else
  #pragma config PLLEN = OFF // PLL Enable (4x PLL enabled)
#endif
#pragma config STVREN = ON // Stack Overflow/Underflow Reset Enable (Stack Overflow or Underflow will cause a Reset)
#pragma config BORV = LO // Brown-out Reset Voltage Selection (Brown-out Reset Voltage (Vbor), low trip point selected.)
#pragma config LVP = ON // Low-Voltage Programming Enable (Low-voltage programming enabled)



//Set default value
//  IO0..IO9 config , modbus address
//__EEPROM_DATA(IOCONFIG_INPUT,IOCONFIG_INPUT,IOCONFIG_INPUT,IOCONFIG_INPUT,IOCONFIG_INPUT,IOCONFIG_INPUT,IOCONFIG_INPUT,IOCONFIG_INPUT);
  __EEPROM_DATA(IOCONFIG_OUTPUT,IOCONFIG_OUTPUT,IOCONFIG_OUTPUT,IOCONFIG_OUTPUT,IOCONFIG_OUTPUT,IOCONFIG_OUTPUT,IOCONFIG_OUTPUT,IOCONFIG_OUTPUT);

__EEPROM_DATA(IOCONFIG_INPUT,IOCONFIG_INPUT,127,0xff,0xff,0xff,0xff,0xff);


unsigned char VRange;  //1 = 1.024V,  2 = 2.048V, 3 = 4.096V else = VDD

unsigned char BadIO; 
SettingStruct Setting;

#define TIMER_100MS  100
near volatile unsigned short Timerms;       //  Interrupt Timer counter in 1 ms
near volatile unsigned short PrimaryTimerms;
near volatile unsigned char TimerDeciSec;    // modbus timer out in 1/10 of sec  in 0.5 ms count
#pragma pack 1
typedef union {
  unsigned short USHORT;
  unsigned char BYTE[2];
}ByteShortUnion;


//near unsigned char CurrentTimer1H;
//near unsigned char CurrentTimer1L;

// serial buffer
#define SERIAL_BUFFER_SIZE 32
near volatile unsigned char InFiFo, OutFiFo;   // these are the buffer pointers for interrupt serial communication; InFiFo ctrl by putch, OutFiFo ctrl by interrupt
near volatile unsigned char RcvInFiFo, RcvOutFiFo;
char SerialBuffer[SERIAL_BUFFER_SIZE];
char RcvSerialBuffer[SERIAL_BUFFER_SIZE];

unsigned char SerialSum;    // use for check sum
unsigned char RcvSerialSum;  // use for check sum verification
bit ModbusOnTransmit;
bit EnableConfigChange;
bit ForceReset;
char ModbusPacketBuffer[SERIAL_BUFFER_SIZE];


const unsigned char     IOMASK[11]={0b00001000,0b00000010,0b00010000,0b01000000,0b10000000,\
                                    0b00000001,0b00000010,0b00000100,0b00001000,0b00010000,0};

const unsigned char NOT_IOMASK[11]={0b11110111,0b11111101,0b11101111,0b10111111,0b01111111,\
                                    0b11111110,0b11111101,0b11111011,0b11110111,0b11101111,0b11111111};

//cap sense mask
const unsigned char CSMASK[10]={0b00001001,0b00001011,0b00001000,0b00000101,0b00000110,\
                                0b00000000,0b00000001,0b00000010,0b00000011,0b00000100};

// MODBUS


// CRC16 source code is in CRC16.c file
extern unsigned short CRC16(unsigned char * puchMsg, unsigned char usDataLen);


unsigned char ModbusFunction;
unsigned char ModbusSlave;
unsigned short ModbusAddress;
unsigned short ModbusData;
volatile unsigned short ModbusCRC;
unsigned char ModbusFramePointer;

unsigned char ModbusBuffer[10];

//MODBUS EXCEPTION
#define ILLEGAL_FUNCTION     1
#define ILLEGAL_DATA_ADDRESS 2
#define ILLEGAL_DATA_VALUE   3
#define SLAVE_DEVICE_FAILURE 4
#define ACKNOWLEDGE          5
#define SLAVE_DEVICE_BUZY    6
#define NEGATIVE_AKNOWLEDGE  7
#define MEMORY_PARITY_ERROR  8


/* Timer utilisation
Timer0  interrupt timer
Timer1  Sensor timer  utility, 
Timer2  Servo   Utility
Timer4  Hardware PWM
*/





  




void SaveSetting(void)
{
  unsigned char  idx;
  unsigned char  * pointer = (unsigned char *) &Setting;

  for(idx=0; idx < sizeof(Setting);idx++)
      eeprom_write(idx, *(pointer++));
}








void SetAnalogConfig(unsigned char Pin)
{
// SET ANALOG PIN
 
 unsigned char ioconfig = Setting.IOConfig[Pin];
 unsigned char _tmp= IOMASK[Pin];
 if(Pin<5)
 {
     TRISB |= _tmp;
     ANSELB |= _tmp;
 }
 else
 {
     TRISA |= _tmp;
     ANSELA |= _tmp;
 }

// SET REFERENCE VOLTAGE
   
  FVRCONbits.ADFVR = ioconfig;
 
// VREF or VDD
  if(ioconfig== IOCONFIG_ANALOGVDD)
    ADCON1bits.ADPREF=0;
  else
    ADCON1bits.ADPREF=3;
}





void SetOutputConfig(unsigned char Pin)
{

    unsigned char ioconfig = Setting.IOConfig[Pin];
 unsigned char _tmp= NOT_IOMASK[Pin];
#ifndef USEASM
 if(Pin<5)
 {
     PORTB &= _tmp;
     TRISB &= _tmp;
     ANSELB &= _tmp;
 }
 else
 {
     PORTA &= _tmp;
     TRISA &= _tmp;
     ANSELA &= _tmp;
 }
 
#else
 if(Pin<5)
 {
    #asm
     movf  SetOutputConfig@_tmp,w
     movwf ??_SetOutputConfig
     movf  ??_SetOutputConfig,w
     movlb 0
     andwf 13,f
     movlb 1
     andwf 13,f
     movlb 3
     andwf 13,f
    #endasm
 }
 else
 {
    #asm
     movf  SetOutputConfig@_tmp,w
     movwf ??_SetOutputConfig
     movf  ??_SetOutputConfig,w
     movlb 0
     andwf 12,f
     movlb 1
     andwf 12,f
     movlb 3
     andwf 12,f
    #endasm
 }
#endif 
}

char SetPWMConfig(unsigned char Pin,unsigned short value)
{

    unsigned char msb;
    unsigned char lsb;  // lsb will hold the CCPIxCON + 2  lsb bits

    msb =  value >>2;
    lsb = value & 3;
    lsb <<=4;
    lsb |= 0b00001100;
    if(Setting.IOConfig[Pin]!=IOCONFIG_PWM)
        return 0;

    if(Pin==0)
    {
        // CCP1
        TRISBbits.TRISB3=0;// output
        CCP1CON= lsb;
        CCPR1L = msb;
    }
    else if(Pin==3)
    {
        TRISBbits.TRISB6=0;// output
        CCP2CON= lsb;
        CCPR2L = msb;
    }
    else if(Pin==8)
    {
        TRISAbits.TRISA3=0;// output
        CCP3CON= lsb;
        CCPR3L = msb;
    }
    else if(Pin==9)
    {
        TRISAbits.TRISA4=0;// output
        CCP4CON= lsb;
        CCPR4L = msb;
    }
    else
    {
        BadIO=0;
        return 0;
    }
    ServoTimer[Pin]=value;
    return 1;

    

}


void SetPullUp(unsigned char Pin, unsigned char PullUp)
{
    if(Pin<5)
    {
        if(PullUp)
         WPUB |= IOMASK[Pin];
        else
         WPUB &= NOT_IOMASK[Pin];
    }
    else BadIO=1;
 
}

void SetInputConfig(unsigned char Pin)
{
    unsigned char _tmp = IOMASK[Pin];
    unsigned char _ntmp= NOT_IOMASK[Pin];
  if(Pin<5)
  {
    TRISB |= _tmp;
    ANSELB &= _ntmp;
  }
  else
  {
    TRISA |= _tmp;
    ANSELA &= _ntmp;
  }

}



void SetIOConfig(unsigned char Pin)
{
    unsigned char loop;
  ConfigUnion ioconfig;

  ioconfig.Config = Setting.IOConfig[Pin];
  ResetIOCycle();

  IOSensorData[Pin].DWORD=0;
  IOSensorData[Pin].WORD[2]=0;


  if(Pin<5)
  {
     IOCounterFlag.Byte & = NOT_IOMASK[Pin];
  }

  if(Pin==0)
  {
      CCP1CON=0;
  }
 if(Pin==3)
 {
      CCP2CON=0;
 }
  if(Pin==8)
      CCP3CON=0;
  if(Pin==9)
      CCP4CON=0;

  if(Pin<5)
  {
  SetPullUp(Pin,1);  // By default pull up is there
  SetIOChange(Pin,0);
  }
  ServoTimer[Pin]=0; // disable Servo

  if(ioconfig.Config<IOCONFIG_INPUT)
  {
      if(Pin<5)
          SetPullUp(Pin,0);
      SetAnalogConfig(Pin);
  }
  else if((ioconfig.SERVO) || (ioconfig.Config==IOCONFIG_OUTPUT))
  {
      SetOutputConfig(Pin);
  }
  else if(ioconfig.Config == IOCONFIG_PWM)
  {
      SetPWMConfig(Pin,0);
  }
  else if(ioconfig.COUNTER)
  {
      if(!ioconfig.PULLUP)
         SetPullUp(Pin,0);
                            SetInputConfig(Pin);
                            SetIOChange(Pin,1);
                            if(Pin==0)
                                IOCounterFlag.IO0=1;
                            if(Pin==1)
                                IOCounterFlag.IO1=1;
                            if(Pin==2)
                                IOCounterFlag.IO2=1;
                            if(Pin==3)
                                IOCounterFlag.IO3=1;
                            if(Pin==4)
                                IOCounterFlag.IO4=1;
  }
  else if((ioconfig.CAP_SENSE) || (ioconfig.Config == IOCONFIG_INPUT))
  {
      if(ioconfig.CAP_SENSE)
      {
         if(Pin>4)
          {BadIO=1;return;}
      }
      if(Pin<5)
          SetPullUp(Pin,0);
      SetInputConfig(Pin);
  }
  else if(ioconfig.DHT)
  {
      if(Pin>4)
       {BadIO=1;return;}
  }
  else
    SetInputConfig(Pin);
}






unsigned short ReadA2D(unsigned char channel)
{

 ByteShortUnion value;
 ADIE=0;                              // clear interrupt flag
 ADIF=0;
 ADON=1;
 ADCON0bits.ADON=1;
 ADCON0bits.CHS=channel;
 __delay_ms(1);
 ADCON0bits.ADGO=1;
 while(ADCON0bits.ADGO==1);
__delay_ms(1);
 ADCON0bits.ADGO=1;
 while(ADCON0bits.ADGO==1);
 value.BYTE[1]=ADRESH;
 value.BYTE[0]=ADRESL;
 return value.USHORT;
}



static void interrupt isr(void){
    static volatile unsigned char _temp;


// timer 1 use by R/C Servo
if(TMR1IE)
if(TMR1IF)
{
    TMR1IF=0;
    if(ServoIndex<5)
    {
    #ifndef USEASM
      PORTB &= ServoMask;
    #else
      {          
        #asm
        movf _ServoMask,w
        andwf _PORTB,f
        #endasm
      }
    #endif
    }
    else
    {
      #ifndef USEASM
        PORTA &= ServoMask;
      #else
      {          
        #asm
        movf _ServoMask,w
        andwf _PORTA,f
        #endasm
      }
      #endif
    }
    TMR1ON=0;
}
    
if(IOCIE)
if(IOCIF)
{
//    IOCBF=0;

    #ifndef USEASM
       _TMR0 = TMR0;
    #else
      {
        #asm
            movf _TMR0,w
            movwf __TMR0
        #endasm
      }
    #endif

    if(IOCBF & DHTFlag)
    {
          // to speed up things, reducing interrupt process ,
          // store timer 0 info into  circular buffer and
          // figure out timing calculation on main program
        #ifndef USEASM

          DHTBitBuffer[DHTBufferIndex++]=_TMR0;
          if(DHTBufferIndex<46)
              DHTBufferIndex++;
          TMR0=0;
        #else
          {
            #asm
               clrf _TMR0
               banksel(_DHTBufferIndex)
               movf _DHTBufferIndex^512,w
               addlw 0x20
               movwf 6
               movlw 2
               movwf 7
               movf _DHTBufferIndex^512,w
               sublw 45
               skipnc
               incf _DHTBufferIndex^512,f
               banksel(0)
               movf __TMR0,w
               movwf 1
            ; IOCBF&=~DHTFlag;
               comf _DHTFlag,w
               movlb 7; select bank 7
               andwf _IOCBF&0x7f,f
            #endasm
          }
        #endif
    }

//}
    #ifndef USEASM
      _temp =(unsigned char) (IOCBF & IOCBN);
    #else
    {
    #asm
        movlb  7 ; select bank7
        movf   22,w
        andwf  21,w
        skipnz
        goto SKIPIOC
        movlb  0
        movwf isr@_temp
    #endasm            
    }
    #endif
    if(_temp&8)
    {
        //IO0
        IOCBFbits.IOCBF3=0;

        if(IOCounterFlag.IO0)
        {
//            IOSensorData[0].DWORD++;
//             COUNTER0++;
// use assembly since variable need to be   big endian
// MODBUS use BIG ENDIAN
// IOSensorData force to be bank3 so it is ^384
// IOSensorData is 6BYTE
// to reduce time on irq just increment ICOUNTER
// and then on main program  add ICOUNTER IOSensorData[0].DWORD++;
            
#asm 
        banksel(_ICOUNTER)
        incf _ICOUNTER^384,f
        btfss _IOCounterReset,3
        goto  INCCOUNTERIO0
        bcf _IOCounterReset,3
        movf (_COUNTER)^384,w
        movwf (_IOSensorData+4)^384
        movf (_COUNTER+1)^384,w
        movwf (_IOSensorData+5)^384
        clrf (_COUNTER)^384
        clrf (_COUNTER+1)^384
INCCOUNTERIO0:
        incf ((_COUNTER+1)^384),f
        skipnz
        incf (_COUNTER^384),f
        movlb 0
#endasm

        }
 
    }

      if(_temp&0x02)
    {
        //IO1
        IOCBFbits.IOCBF1=0;

        if(IOCounterFlag.IO1)
        {
//           IOSensorData[1].DWORD++;
//            COUNTER1++;
// use assembly since variable need to be   big endian
//
//
//
// to reduce time on irq just increment ICOUNTER
// and then on main program  add ICOUNTER IOSensorData[1].DWORD++;

#asm
        banksel(_ICOUNTER)
        incf (_ICOUNTER+1)^384,f
        btfss _IOCounterReset,4
        goto  INCCOUNTERIO1
        bcf _IOCounterReset,4
        movf (_COUNTER+2)^384,w
        movwf (_IOSensorData+4+ARRAY1)^384
        movf (_COUNTER+3)^384,w
        movwf (_IOSensorData+5+ARRAY1)^384
        clrf (_COUNTER+2)^384
        clrf (_COUNTER+3)^384
INCCOUNTERIO1:
        incf ((_COUNTER+3)^384),f
        skipnz
        incf ((_COUNTER+2)^384),f
        movlb 0
#endasm

        }
    }

    if(_temp&0x10)
    {
        //IO2
        IOCBFbits.IOCBF4=0;

        if(IOCounterFlag.IO2)
        {
//           IOSensorData[2].DWORD++;
//            COUNTER2++;
// use assembly since variable need to be   big endian
// to reduce time on irq just increment ICOUNTER
// and then on main program  add ICOUNTER IOSensorData[2].DWORD++;

#asm
        banksel(_ICOUNTER)
        incf (_ICOUNTER+2)^384,f
        btfss _IOCounterReset,5
        goto  INCCOUNTERIO2
        bcf _IOCounterReset,5
        movf (_COUNTER+4)^384,w
        movwf (_IOSensorData+4+ARRAY2)^384
        movf (_COUNTER+5)^384,w
        movwf (_IOSensorData+5+ARRAY2)^384
        clrf (_COUNTER+4)^384
        clrf (_COUNTER+5)^384                  
INCCOUNTERIO2:
        incf ((_COUNTER+5)^384),f
        skipnz
        incf ((_COUNTER+4)^384),f
        movlb 0
#endasm

        }
 
    }

    if(_temp&0x40)
    {
        //IO3
        IOCBFbits.IOCBF6=0;

        if(IOCounterFlag.IO3)
        {
//           IOSensorData[3].DWORD++;
//            COUNTER3++;
// use assembly since variable need to be   big endian
// to reduce time on irq just increment ICOUNTER
// and then on main program  add ICOUNTER IOSensorData[3].DWORD++;

#asm
        
        banksel(_ICOUNTER)
        incf (_ICOUNTER+3)^384,f
        btfss _IOCounterReset,6
        goto  INCCOUNTERIO3
        bcf _IOCounterReset,6
        movf (_COUNTER+6)^384,w
        movwf (_IOSensorData+4+ARRAY3)^384
        movf (_COUNTER+7)^384,w
        movwf (_IOSensorData+5+ARRAY3)^384
        clrf (_COUNTER+6)^384
        clrf (_COUNTER+7)^384
INCCOUNTERIO3:
        incf ((_COUNTER+7)^384),f
        skipnz
        incf ((_COUNTER+6)^384),f
        movlb 0
#endasm

        }
    }

      if(_temp&0x80)
    {
        //IO4
        IOCBFbits.IOCBF7=0;

        if(IOCounterFlag.IO4)
        {
//           IOSensorData[4].DWORD++;
//            COUNTER4++;
          // use assembly since variable need to be   big endian
// to reduce time on irq just increment ICOUNTER
// and then on main program  add ICOUNTER IOSensorData[4].DWORD++;

#asm
        banksel(_ICOUNTER)
        incf (_ICOUNTER+4)^384,f
        btfss _IOCounterReset,7
        goto  INCCOUNTERIO4
        bcf _IOCounterReset,7
        movf (_COUNTER+8)^384,w
        movwf (_IOSensorData+4+ARRAY4)^384
        movf (_COUNTER+9)^384,w
        movwf (_IOSensorData+5+ARRAY4)^384
        clrf (_COUNTER+8)^384
        clrf (_COUNTER+9)^384
INCCOUNTERIO4:
        incf ((_COUNTER+9)^384),f
        skipnz
        incf ((_COUNTER+8)^384),f
        movlb 0
#endasm

        }
    }
}

asm ("SKIPIOC:");   // fast lane to skip IOC

// this is the second test to remove glitch
// timer 1 use by R/C Servo

    if(TMR1IE)
    if(TMR1IF)
{
    TMR1IF=0;
    if(ServoIndex<5)
    {
     #ifndef USEASM
      PORTB &= ServoMask;
     #else
        #asm
                movf _ServoMask,w
                andwf _PORTB,f
        #endasm
     #endif
    }
    else
    {
     #ifndef USEASM        
      PORTA &= ServoMask;
     #else
        #asm
                movf _ServoMask,w
                andwf _PORTA,f
        #endasm
     #endif
    }
    TMR1ON=0;
  }
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

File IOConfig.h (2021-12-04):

#ifndef IOCONFIG
#define IOCONFIG

//  IOCONFIG
// ATTENTION IOCONFIG_ANALOG...  VALUE ARE DIRECTLY RELATED TO FVRCON.ADFVR
#define IOCONFIG_ANALOGVDD 0  // don't change
#define IOCONFIG_ANALOG1V  1  //   "     "
#define IOCONFIG_ANALOG2V  2  //   "     "
#define IOCONFIG_ANALOG4V  3  //   "     "
#define IOCONFIG_INPUT     4
#define IOCONFIG_INPUT_PULLUP 5
#define IOCONFIG_OUTPUT    6
#define IOCONFIG_PWM       7

#define IOCONFIG_CAP_SENSE_OFF    8
#define IOCONFIG_CAP_SENSE_LOW 	  9
#define IOCONFIG_CAP_SENSE_MEDIUM 10
#define IOCONFIG_CAP_SENSE_HIGH   11


#define IOCONFIG_DHT11     16
#define IOCONFIG_DHT22     17
#define IOCONFIG_DS18B20   32
#define IOCONFIG_SERVO     64
#define IOCONFIG_COUNTER   128
#define IOCONFIG_COUNTER_PULLUP 129

typedef union {
    struct {
        unsigned PULLUP            :1;
        unsigned NO_USED           :2;
        unsigned CAP_SENSE         :1;
        unsigned DHT               :1;
        unsigned DS18B20           :1;
        unsigned SERVO             :1;
        unsigned COUNTER           :1;
    };
    unsigned char Config;
} ConfigUnion;





// if we use a RS485 DRIVER without the need to switch
// direction, we wil have an other input

extern const unsigned char IOMASK[11];
extern const unsigned char NOT_IOMASK[11];
extern const unsigned char CSMASK[10];
#define INPUT_COUNT 10

#define IO0 RB3
#define IO0_TRIS  TRISBbits.TRISB3
#define IO0_ANSEL ANSELBbits.ANSB3
#define IO0_AN_CHANNEL 9
#define IO0_PULLUP WPUBbits.WPUB3


#define IO1 RB1
#define IO1_TRIS  TRISBbits.TRISB1
#define IO1_ANSEL ANSELBbits.ANSB1
#define IO1_AN_CHANNEL 11
#define IO1_PULLUP WPUBbits.WPUB1

#define IO2 RB4
#define IO2_TRIS  TRISBbits.TRISB4
#define IO2_ANSEL ANSELBbits.ANSB4
#define IO2_AN_CHANNEL 8
#define IO2_PULLUP WPUBbits.WPUB4

#define IO3 RB6
#define IO3_TRIS  TRISBbits.TRISB6
#define IO3_ANSEL ANSELBbits.ANSB6
#define IO3_AN_CHANNEL 5
#define IO3_PULLUP WPUBbits.WPUB6

#define IO4 RB7
#define IO4_TRIS  TRISBbits.TRISB7
#define IO4_ANSEL ANSELBbits.ANSB7
#define IO4_AN_CHANNEL 6
#define IO4_PULLUP WPUBbits.WPUB7

#define IO5 RA0
#define IO5_TRIS  TRISAbits.TRISA0
#define IO5_ANSEL ANSELAbits.ANSA0
#define IO5_AN_CHANNEL 0


#define IO6 RA1
#define IO6_TRIS  TRISAbits.TRISA1
#define IO6_ANSEL ANSELAbits.ANSA1
#define IO6_AN_CHANNEL 1

#define IO7 RA2
#define IO7_TRIS  TRISAbits.TRISA2
#define IO7_ANSEL ANSELAbits.ANSA2
#define IO7_AN_CHANNEL 2

#define IO8 RA3
#define IO8_TRIS  TRISAbits.TRISA3
#define IO8_ANSEL ANSELAbits.ANSA3
#define IO8_AN_CHANNEL 3

#define IO9 RA4
#define IO9_TRIS  TRISAbits.TRISA4
#define IO9_ANSEL ANSELAbits.ANSA4
#define IO9_AN_CHANNEL 4



typedef struct{
unsigned char IOConfig[INPUT_COUNT];
unsigned char SlaveAddress;
}SettingStruct;


extern SettingStruct Setting;
#define BAUD 9600
//#define BAUD 57600
//#define BAUD 19200
//#define BAUD 38400
//#define BAUD 57600
//#define BAUD 115200

#define USE_EXTERNAL_XTAL

#ifndef _XTAL_FREQ
#define _XTAL_FREQ 32000000
#endif

#endif

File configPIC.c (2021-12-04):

/**************************************
PIC Multi-Purpose Modbus

configuration application

This program is used to set the Modbus Address of the PIC Multi-purpose module

it will also set the IO pin mode configuration

to compile:

   gcc -I /usr/include/modbus configPIC.c -o configPIC  -l modbus

libmodbus is needed

 please check url: http://libmodbus.org

 You could  download libmodbus on the Raspberry Pi using

    sudo apt-get install libmodbus5 libmodbus-dev

PIC Multi-Purpose  configPIC  program
Daniel Perron (c)  April, 2014
V1.0
***************************************/

////////////////////////////////////  GPL LICENSE ///////////////////////////////////


/*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
    You should have received a copy of the GNU General Public License
    along with this program.  If not, see <http://www.gnu.org/licenses/>.
*/

#include <stdio.h>
#include <unistd.h>
#include <string.h>
#include <stdlib.h>
#include <errno.h>
#include <termios.h>
#include <modbus.h>
#include <ctype.h>

#define DEFAULT_DEVICE "/dev/ttyUSB0"

typedef struct
{
unsigned short     mode;
unsigned char * asciiMode;
unsigned char SpecialFunctions;
}IOConfigStruct;

char device[256];
int Baud = 9600;

unsigned char scanOnly=0;
unsigned char CurrentSlaveAddress=255;
unsigned char CurrentSlaveId=0;
unsigned char CurrentSlaveIOCount=0;
long  timeout=0;

int IsModuleFound(modbus_t * mb, unsigned char  SlaveAddress);
unsigned char selectModule(modbus_t * mb);


#define IOCONFIG_ANALOGVDD 0
#define IOCONFIG_ANALOG1V  1
#define IOCONFIG_ANALOG2V  2
#define IOCONFIG_ANALOG4V  3
#define IOCONFIG_INPUT     4
#define IOCONFIG_INPUT_PULLUP 5
#define IOCONFIG_OUTPUT    6
#define IOCONFIG_PWM       7
#define IOCONFIG_CAP_SENSE_OFF    8
#define IOCONFIG_CAP_SENSE_LOW 	  9
#define IOCONFIG_CAP_SENSE_MEDIUM 10
#define IOCONFIG_CAP_SENSE_HIGH   11


#define IOCONFIG_DHT11     16
#define IOCONFIG_DHT22     17
#define IOCONFIG_DS18B20   32
#define IOCONFIG_SERVO     64
#define IOCONFIG_COUNTER   128
#define IOCONFIG_COUNTER_PULLUP   129


IOConfigStruct  configInfo[]={
  {  IOCONFIG_ANALOGVDD, "ANALOGVDD",0},
  {  IOCONFIG_ANALOG1V, "ANALOG1V",0},
  {  IOCONFIG_ANALOG2V, "ANALOG2V",0},
  {  IOCONFIG_ANALOG4V, "ANALOG4V",0},
  {  IOCONFIG_INPUT, "INPUT",0},
  {  IOCONFIG_INPUT_PULLUP, "INPUT PULLUP",1},
  {  IOCONFIG_OUTPUT, "OUTPUT",0},
  {  IOCONFIG_PWM,"PWM",2},
  {  IOCONFIG_CAP_SENSE_OFF, "CAP SENSE OFF",1},
  {  IOCONFIG_CAP_SENSE_LOW, "CAP SENSE LOW",1},
  {  IOCONFIG_CAP_SENSE_MEDIUM, "CAP SENSE MEDIUM",1},
  {  IOCONFIG_CAP_SENSE_HIGH, "CAP SENSE HIGH",1},
  {  IOCONFIG_DHT11, "DHT11",1},
  {  IOCONFIG_DHT22, "DHT22",1},
  {  IOCONFIG_DS18B20, "DS18B20",0},
  {  IOCONFIG_SERVO, "R/C SERVO",0},
  {  IOCONFIG_COUNTER, "COUNTER",1},
  {  IOCONFIG_COUNTER_PULLUP, "COUNTER PULLUP",1},
  {65535, "",0}};

unsigned char  IsPinHaveSpecialFunctions[]={1,1,1,1,1,0,0,0,0,0};
unsigned char  IsPinHavePWM[]=             {1,0,0,1,0,0,0,0,1,1};

uint16_t  MB_Version;


int moduleID =0;

int GetConfigIndex(int mode)
{
   int loop;
   for(loop=0;;loop++)
     {
       if(configInfo[loop].mode== 65535) return -1;
       if(configInfo[loop].mode== mode) return loop;
     }
 return -1;
}



int IsConfigValidOnPin(int mode, int Pin)
{
    int  configIndex;

    if(moduleID == 0) return 0;

    if(Pin<0) return 0;

    if(mode == IOCONFIG_COUNTER_PULLUP)
     {
      if(moduleID != 0x653A)
          if(Pin>1) return 0;
     }

    if(Pin>9) return 0;

    configIndex = GetConfigIndex(mode);

    if(configIndex <0) return 0;

    if(mode == IOCONFIG_PWM)
        return IsPinHavePWM[Pin];


    if(configInfo[configIndex].SpecialFunctions)
      if(IsPinHaveSpecialFunctions[Pin]==0)
         {
            return 0;
         }

    return 1;
}



char * configModeInText(int IOConfigMode)
{
   int loop;

   loop = GetConfigIndex(IOConfigMode);

//    printf("%03d ",IOConfigMode);

   if(loop>=0)
      return configInfo[loop].asciiMode;
   return "???";
}


void decodeArg(int argc, char * argv[])
{
  int loop;

  for(loop=1;loop<argc;loop++)
   {
    if(strcasecmp(argv[loop],"-scan")==0)
      scanOnly=1;
    if(strcmp(argv[loop],"-d")==0)
      {
       loop++;
       strcpy(device,argv[loop]);
      }
    if(strcmp(argv[loop],"-b")==0)
      {
        loop++;
        Baud=atoi(argv[loop]);
        if(Baud >0)
        if(timeout == 0)
        {
          timeout = (1000000 / Baud)*576;
        }

      }
    if(strcmp(argv[loop],"-t")==0)
       {
         loop++;
         timeout = atol(argv[loop]);
       }
    if(strcmp(argv[loop],"--help")==0)
      {
        printf("usage:\nconfigPIC  [-scan][-d DeviceName][-b BaudRate] [-t response_Delay_us]\n");
        exit(0);
      }
  }
}


void changeAddress(modbus_t * mb)
{

  int  new_Address;

  printf("\n=======Change Address\n");





  if(CurrentSlaveAddress == 255)
     selectModule(mb);
  else
     if(!IsModuleFound(mb,CurrentSlaveAddress))
       selectModule(mb);

  if(CurrentSlaveAddress==255) return;


   printf("\nEnter new Slave Address for this module (1..127) ?");

   if(scanf("%d",&new_Address)!=1)
      printf("Invalid value!  configuration not change.\n");
   else
     {
       if(new_Address>0)
        if(new_Address<128)
        {
          if(IsModuleFound(mb,new_Address))
          {
      	   modbus_set_slave(mb,CurrentSlaveAddress);
           printf("Address already used!\nConfiguration not changes.\n");
          }
          else
          {
   	   modbus_set_slave(mb,CurrentSlaveAddress);
           // unlock confiration
           modbus_write_register(mb,0x1ff,0x5678);
           modbus_write_register(mb,160,new_Address);
           printf("Module is now on Address %d\n",new_Address);
           CurrentSlaveAddress=new_Address;
          }
        }
      else
       printf("Invalid value!  configuration not change.\n");
     }
   usleep(1000000); // delay needed to store data into eerom
   IsModuleFound(mb,CurrentSlaveAddress);

}


unsigned short  getConfigMode(modbus_t * mb, int Pin)
{
     uint16_t MB_Register;
     if( modbus_read_registers(mb,0x100+Pin,1,&MB_Register) < 0)
        return 65535;
     return MB_Register;
}


int IsModuleFound(modbus_t * mb, unsigned char  SlaveAddress)
{
   int rcode;
   uint16_t  MB_Register;

   if(SlaveAddress >127) return 0;

   modbus_set_slave(mb,SlaveAddress);
   if (modbus_read_registers(mb,251,1,&MB_Register) <0)
       return 0;
   if (modbus_read_registers(mb,250,1,&MB_Version) <0)
       MB_Version=0;

   if(MB_Register == 0x6532)
     return 0x6532;
   if(MB_Register == 0x653A)
     return 0x653A;
   return 0;
}
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

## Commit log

2014-05-19 RC Servo glitch
2014-09-25 Correct for PCB version
    [MultiIO_10.GBL, MultiIO_10.GBO, MultiIO_10.GBS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]
2014-11-10 fix ds18b20 and add WebRelais.html
    [configPIC.c, test.c]
2017-10-10 Add Documentation
    [Modbus address map.xlsx, MultiIO_10.xlsx]
2020-04-22 fix for newer modbus library
    [configPIC.c]
2020-05-01 label on IO
    [MultiIO10LabelV2.xlsx]
2021-11-17 fix configPIC counter pullup
    [configPIC.c]

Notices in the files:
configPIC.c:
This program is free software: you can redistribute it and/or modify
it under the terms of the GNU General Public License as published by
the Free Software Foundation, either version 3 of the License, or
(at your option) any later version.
